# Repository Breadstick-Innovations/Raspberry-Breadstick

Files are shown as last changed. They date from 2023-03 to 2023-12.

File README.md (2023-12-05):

# Raspberry Breadstick
An RP2040 development board compatible with CircuitPython, MicroPython, and Arduino!
## Campaign Now Live!→ https://www.crowdsupply.com/breadstick-innovations/raspberry-breadstick
Rev0.2-17
Rev0.2 Render - Small Production Run Underway!
## A Breadstick for your Breadboard!
- Spaced out I/O pins eliminate long jumper wires
- RP2040 with 16MB of Flash Memory
- 24 SK9822 addressable RGB LEDs (Clock + Data) that are DotStar compatible
- 6-Axis IMU LSM6DSMTR (3-Axis Accellerometer + 3-Axis Gyroscope)
Rev0.2-Ortho-5
Rev0.2-25
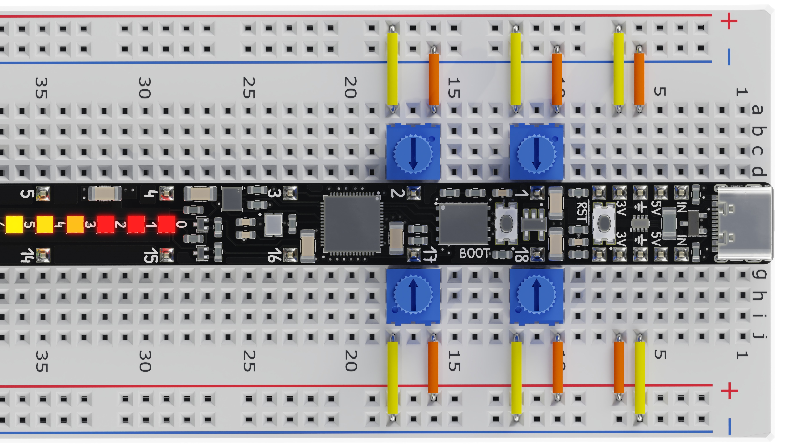
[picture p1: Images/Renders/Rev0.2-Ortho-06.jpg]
Rev0.2-Ortho-06

Rev0.2 Renders - Small Production Run Underway!
## Rev0.1 Demo Video
Rev0.1 Prototype Youtube (https://www.youtube.com/watch?v=IzdXLQIp9vg)
## Schematic
### RP2040 GPIO to Pin Definitions
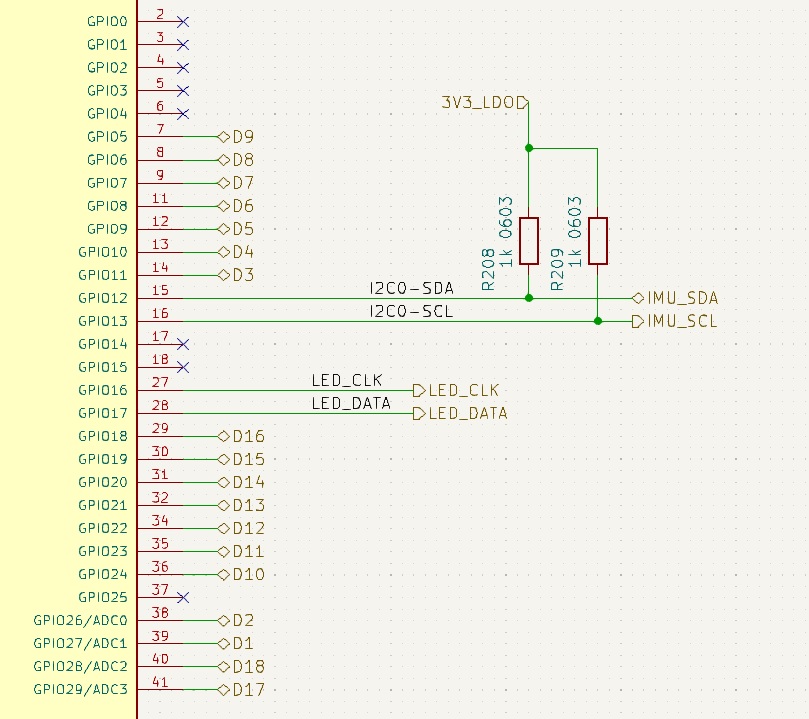
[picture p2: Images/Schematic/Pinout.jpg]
Pinout

### Overview
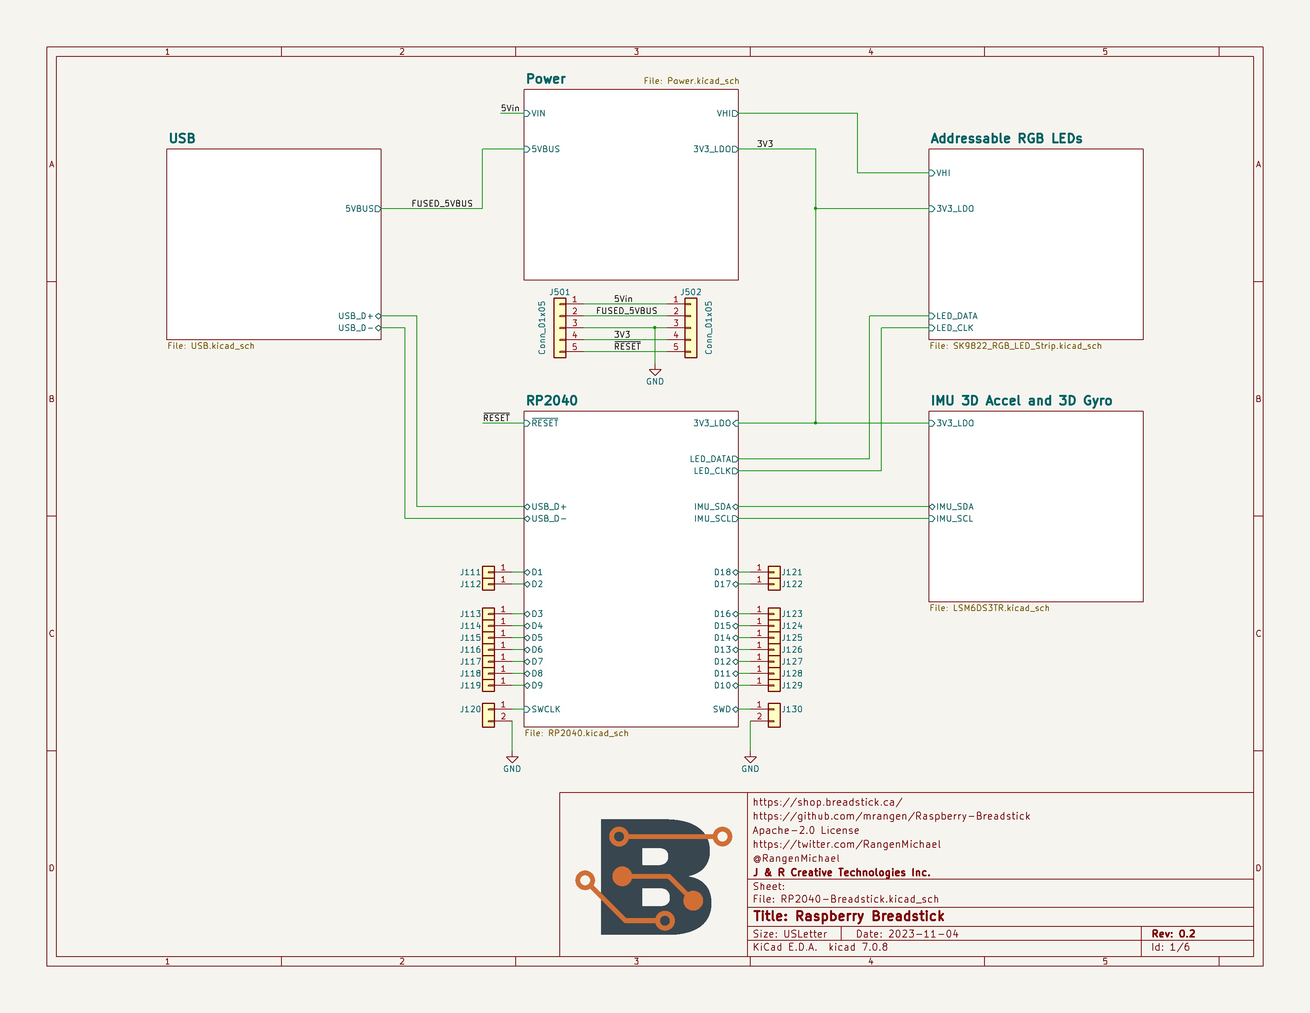
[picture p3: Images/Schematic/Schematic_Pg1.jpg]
Schematic_Pg1

### RP2040 Microcontroller
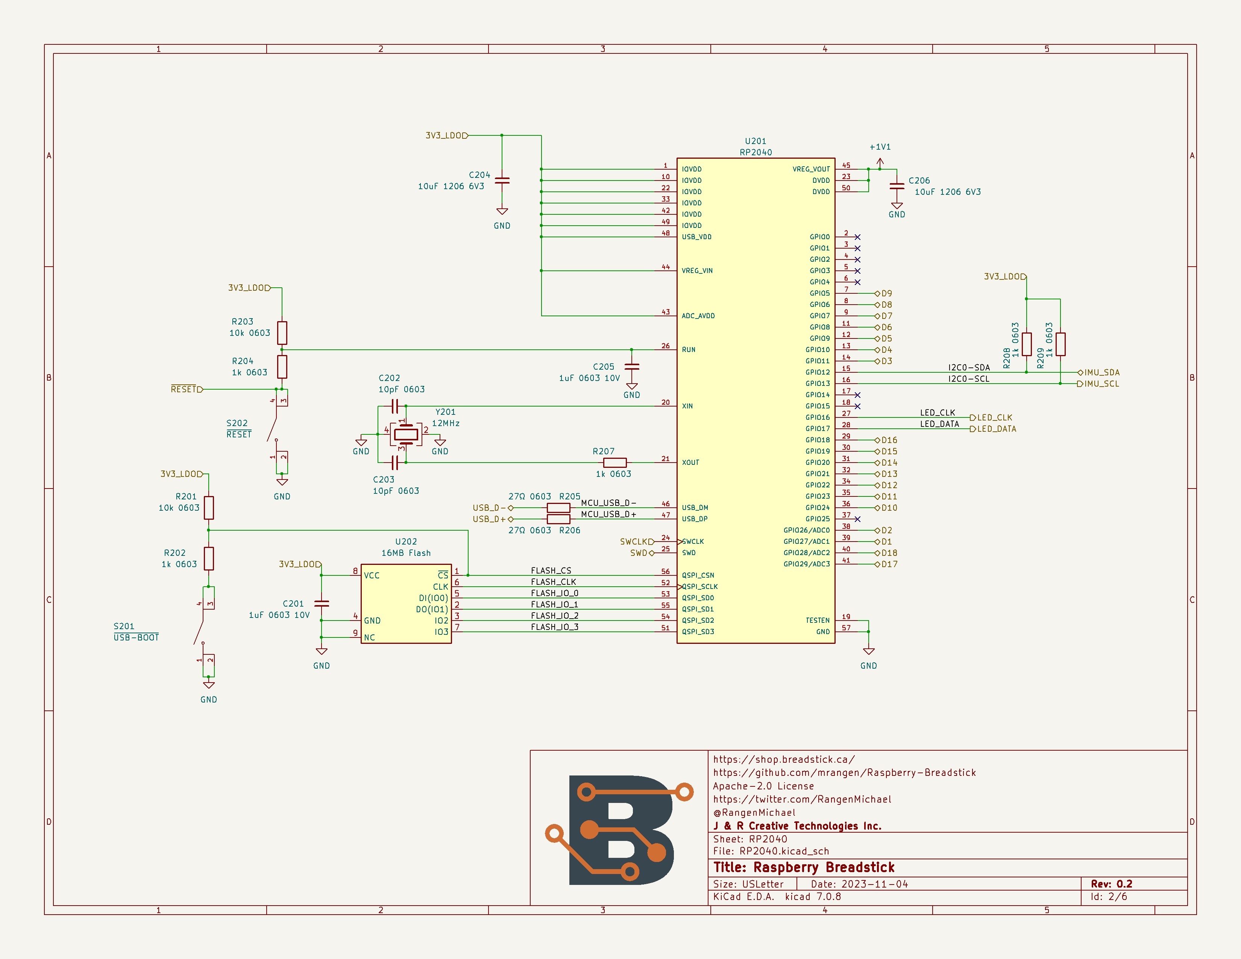
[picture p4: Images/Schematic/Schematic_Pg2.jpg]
Schematic_Pg2.

### SK9822 RGB LEDs
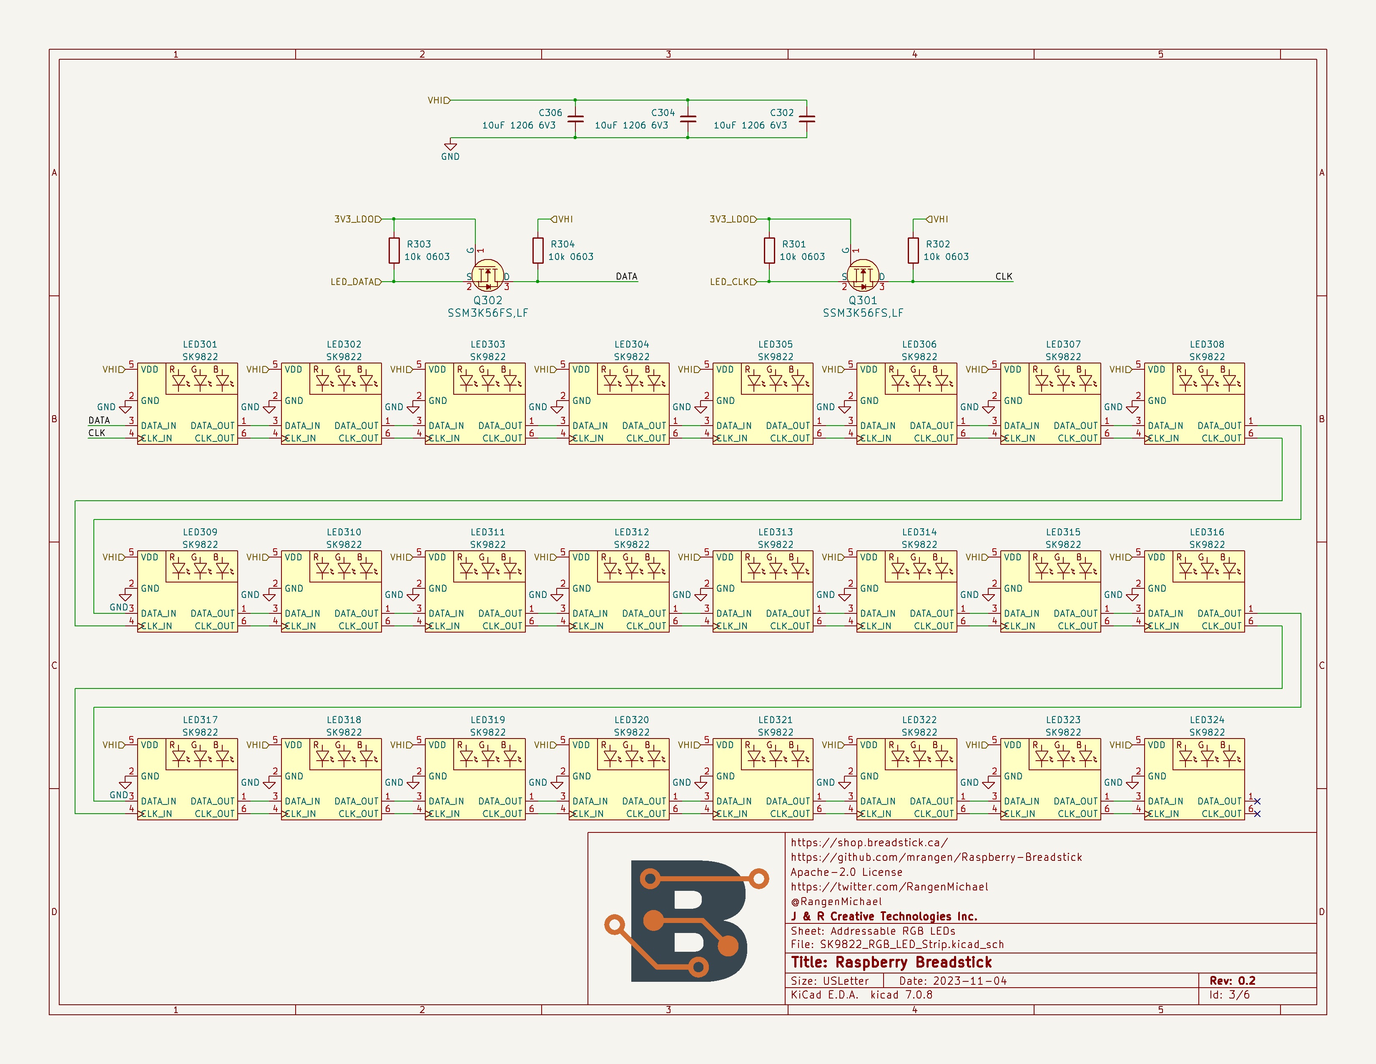
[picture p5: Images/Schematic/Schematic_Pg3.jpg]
Schematic_Pg3

### LSM6DSMTR 6-Axis IMU
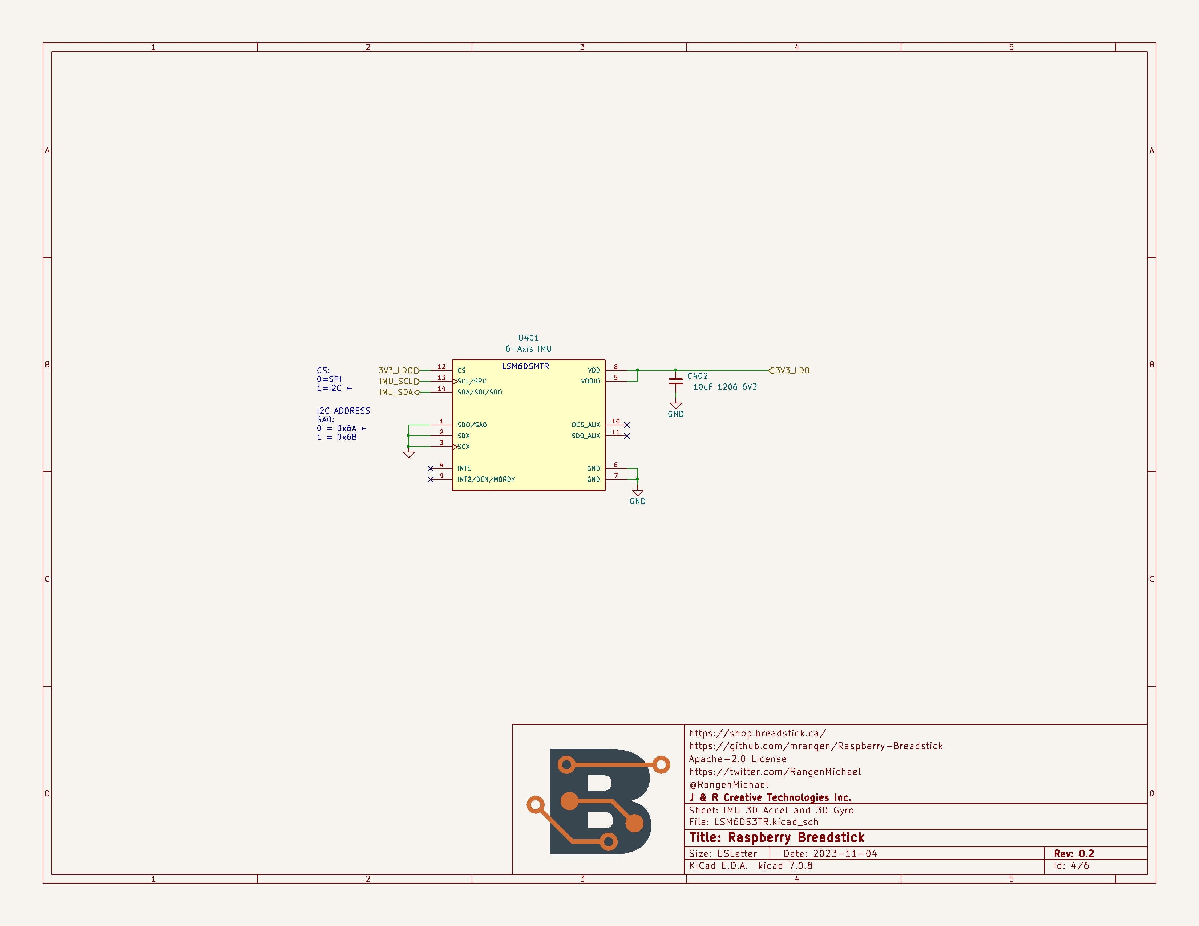
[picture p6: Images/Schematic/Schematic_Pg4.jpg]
Schematic_Pg4

### Power
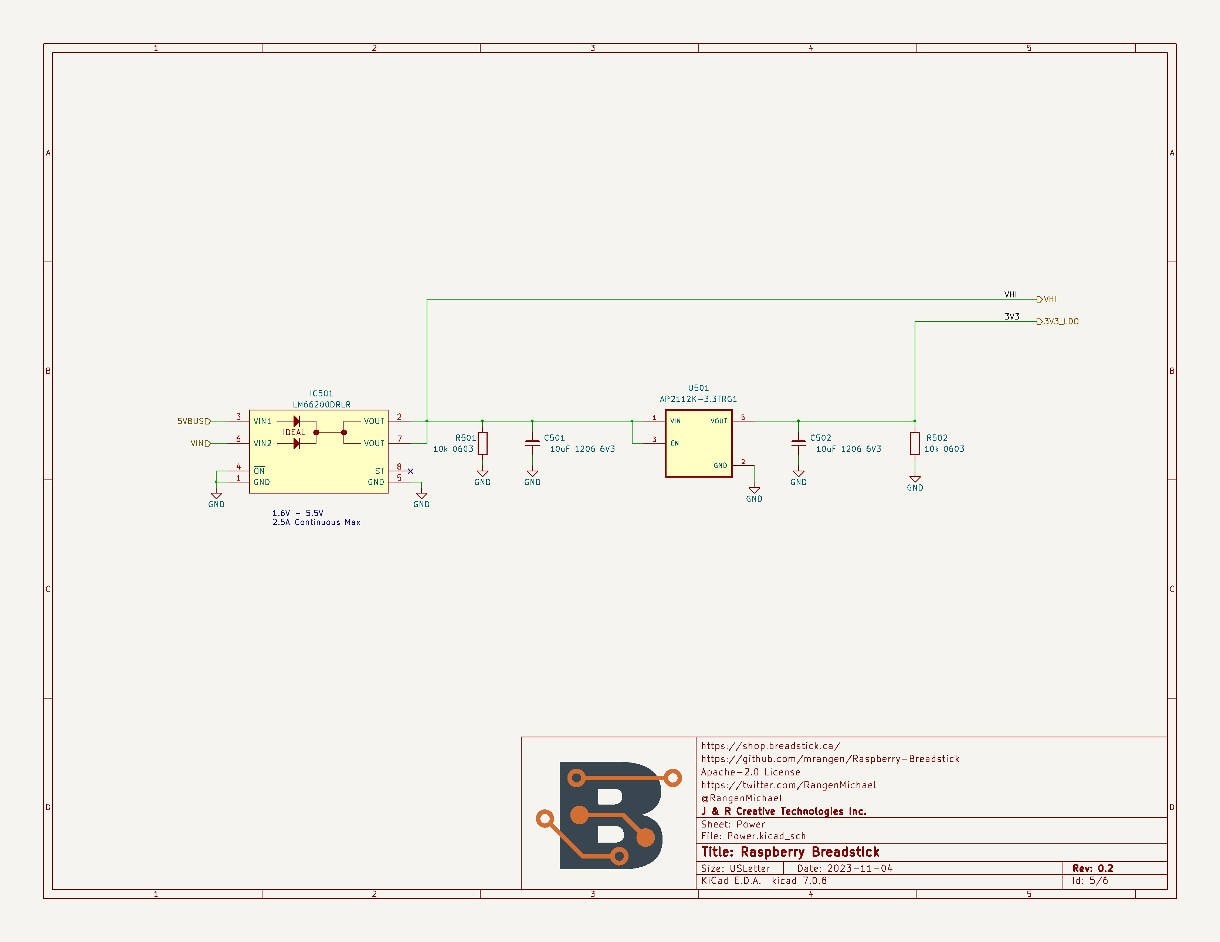
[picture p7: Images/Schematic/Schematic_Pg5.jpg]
Schematic_Pg5

### USB-C
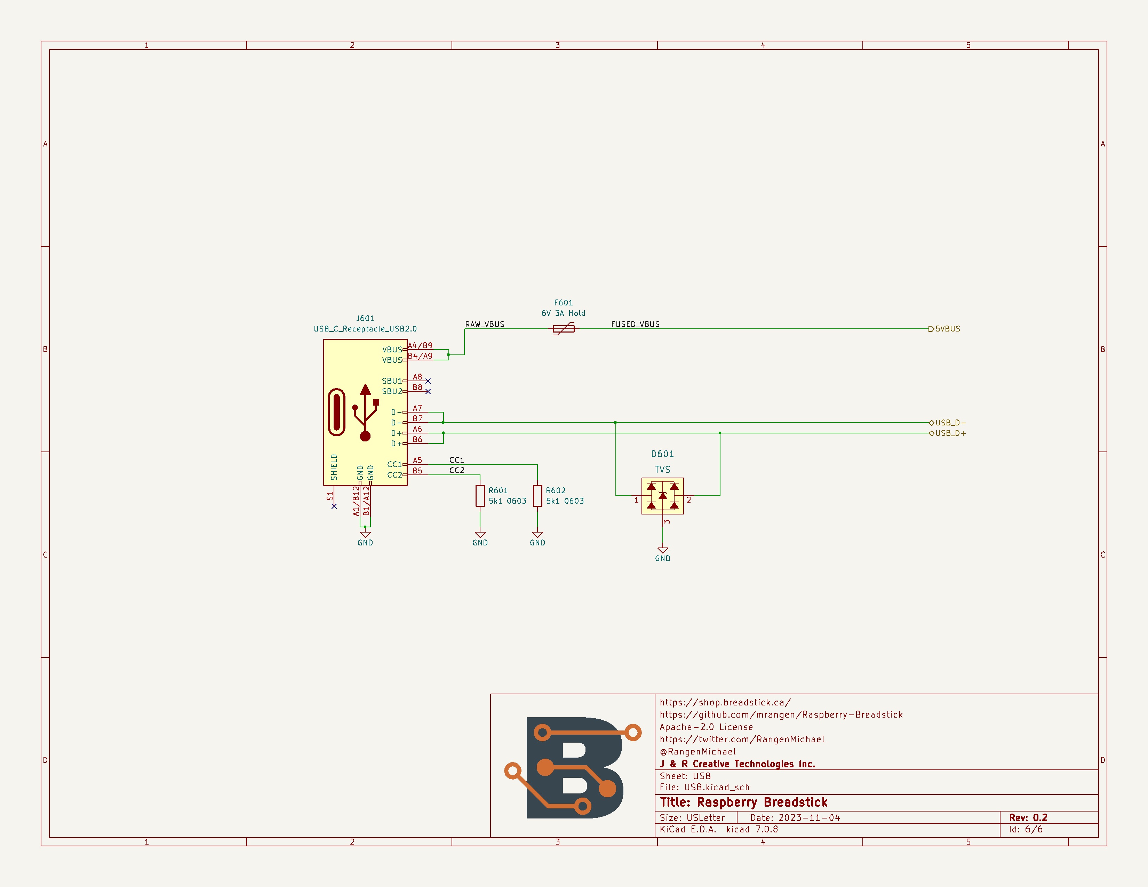
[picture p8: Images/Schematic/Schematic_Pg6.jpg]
Schematic_Pg6


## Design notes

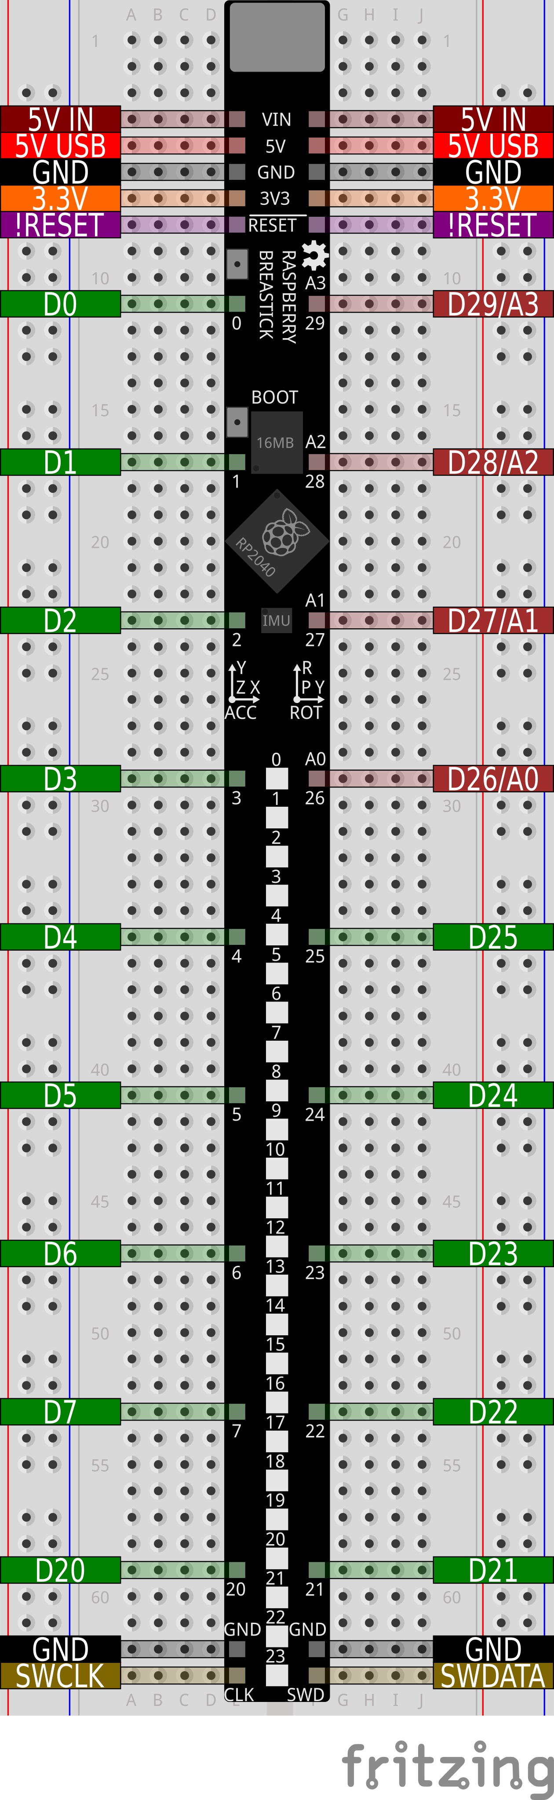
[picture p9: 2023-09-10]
RP2040-Breadstick/Pinout Diagram/RaspberryBreadstickPinout.jpg

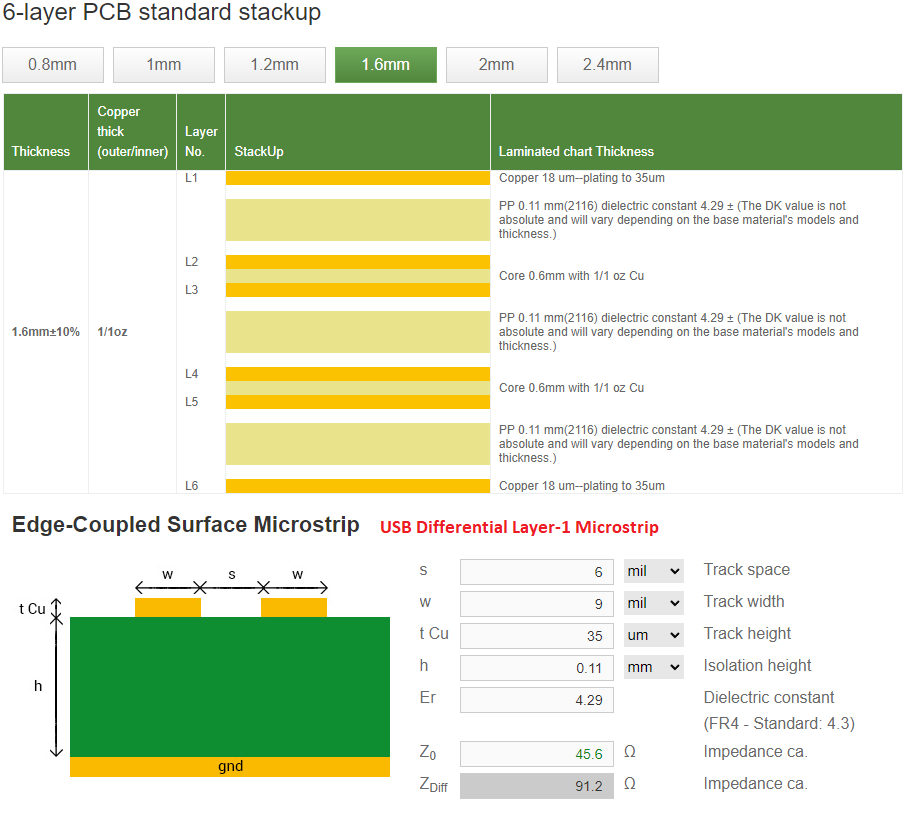
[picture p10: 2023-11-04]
6-Layer Stackup and Controlled Impedance.png

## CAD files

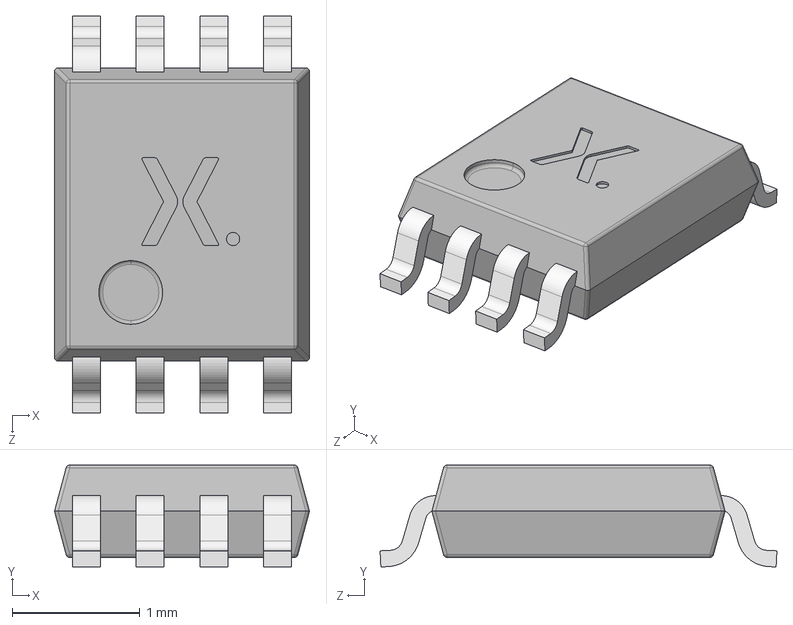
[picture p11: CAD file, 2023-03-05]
RP2040-Breadstick/Snap EDA/74AXP2T45DCH/74AXP2T45DCH.stp
2.00 x 0.8 x 3.11 mm
SOT765 Mold body
SOT765 Lead x 8

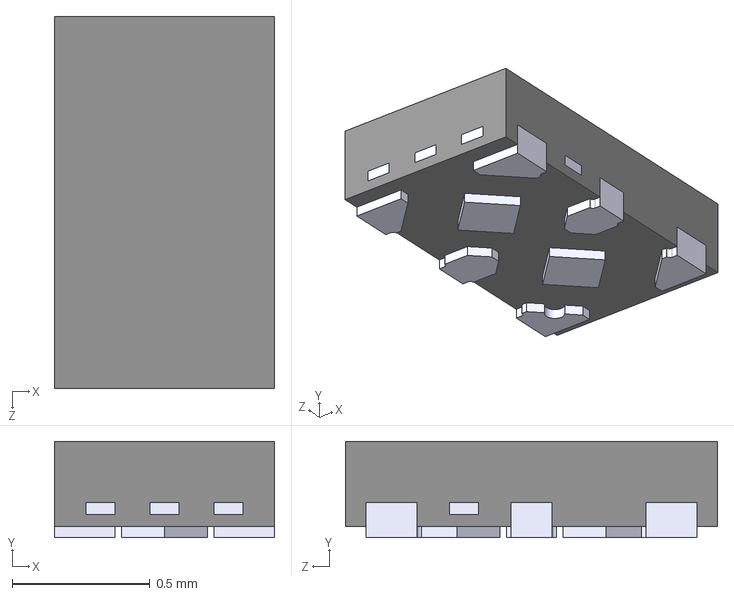
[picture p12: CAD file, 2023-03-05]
RP2040-Breadstick/Snap EDA/74AXP2T45GXX/74AXP2T45GXX.STEP
0.8 x 0.35 x 1.35 mm

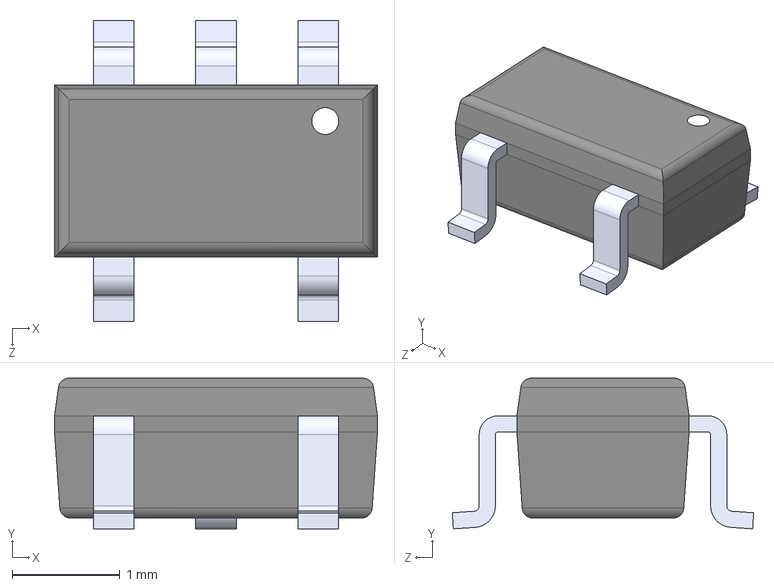
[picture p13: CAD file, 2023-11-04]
RP2040-Breadstick/Snap EDA/AP2112K-3.3TRG1/AP2112K-3.3TRG1.step
3.00 x 1.40 x 2.80 mm

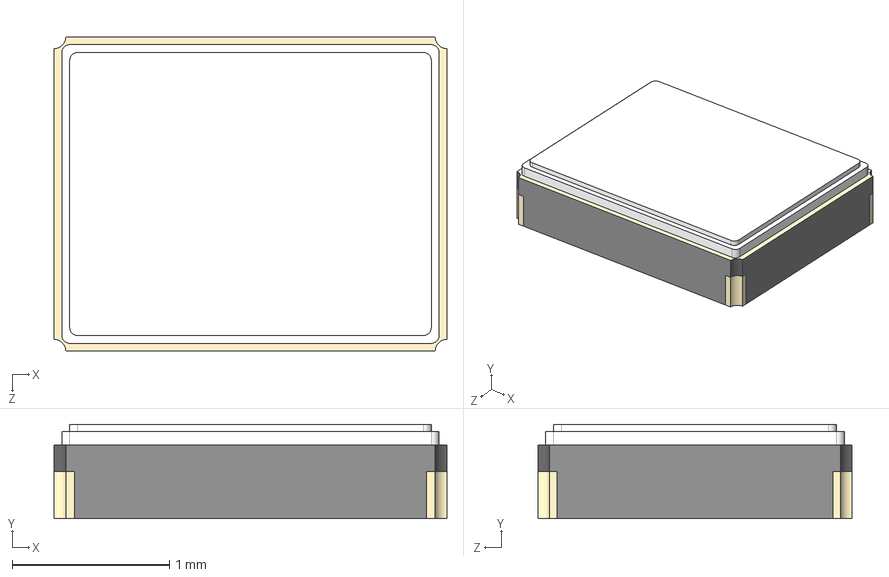
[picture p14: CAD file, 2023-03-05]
RP2040-Breadstick/Snap EDA/ECS-120-10-36Q-ES-TR/ECS-120-10-36Q-ES-TR.step
2.50 x 0.6 x 2.00 mm

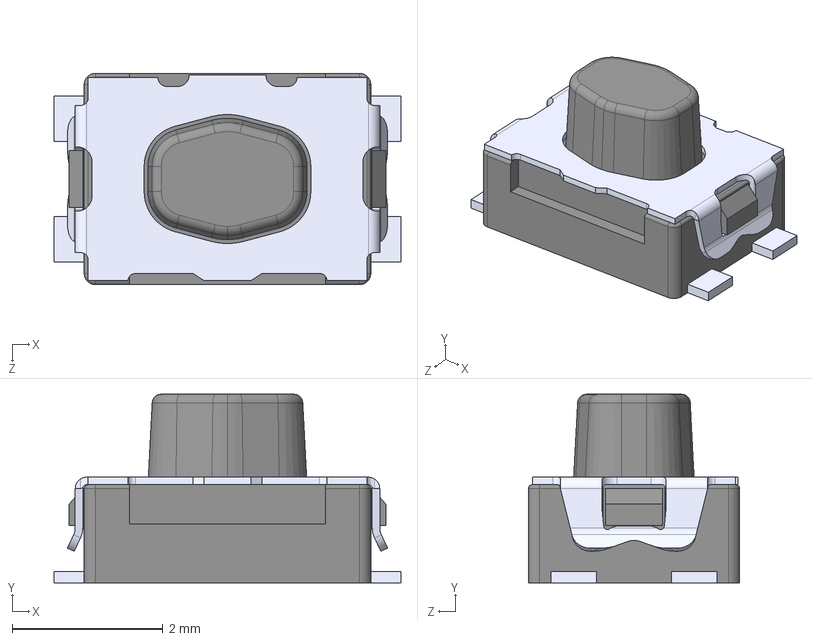
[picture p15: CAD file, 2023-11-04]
RP2040-Breadstick/Snap EDA/KMR731NGLFS/KMR731NGLFS.step
4.60 x 2.50 x 2.80 mm

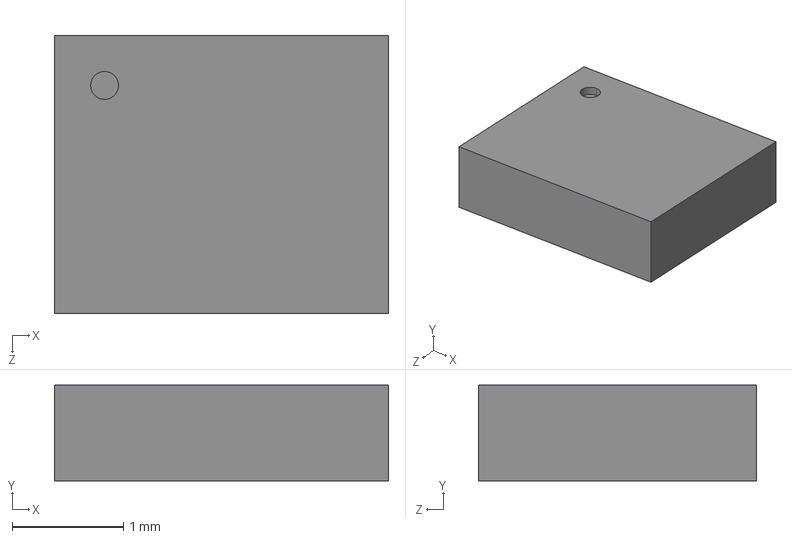
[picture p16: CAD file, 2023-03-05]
RP2040-Breadstick/Snap EDA/LSM6DSMTR/LSM6DSMTR.step
3.00 x 0.86 x 2.50 mm

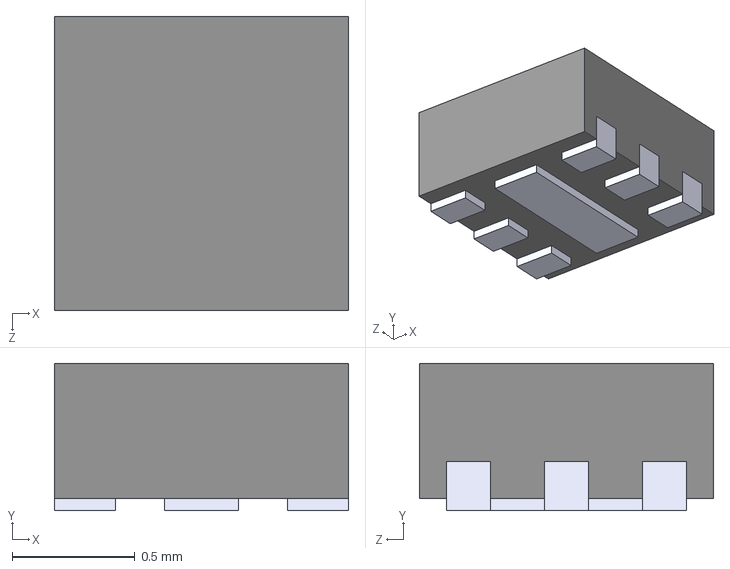
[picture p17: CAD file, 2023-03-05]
RP2040-Breadstick/Snap EDA/MIC5528-3.3YMT-TR/MIC5528-3.3YMT-TR.step
1.20 x 0.6 x 1.20 mm

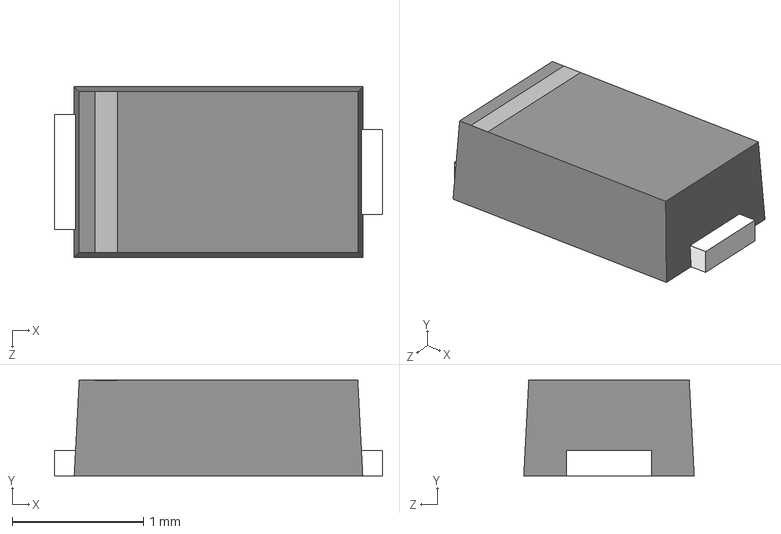
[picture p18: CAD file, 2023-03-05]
RP2040-Breadstick/Snap EDA/MICROSMP_DO-219AD/V2PM15HM3_H.step
2.50 x 0.73 x 1.30 mm

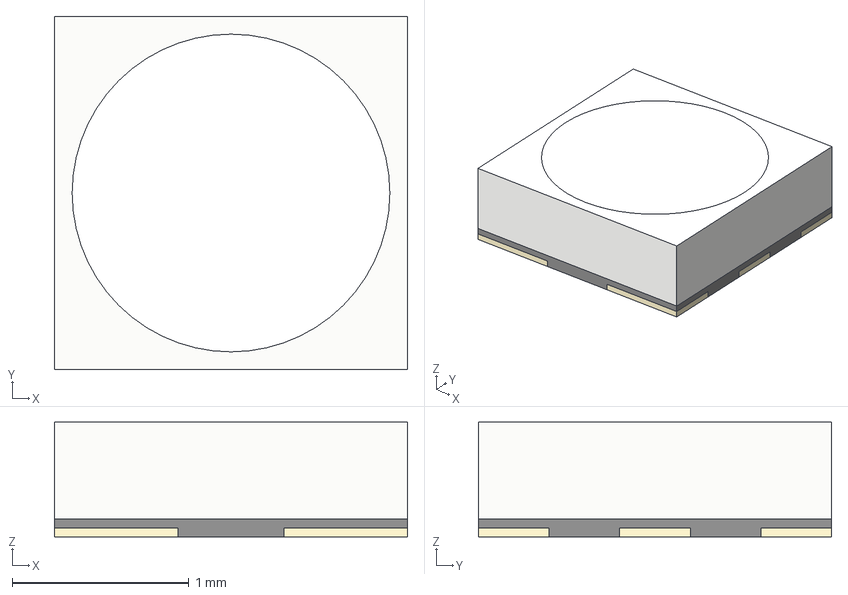
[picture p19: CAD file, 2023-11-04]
RP2040-Breadstick/Snap EDA/SK9822-2020 RGB LED v2.step
2.00 x 2.00 x 0.65 mm
SK9822-2020 RGB LED v2 v6
SK9822-2020 RGB LED v2 v007
SK9822-2020 RGB LED v2 v008
SK9822-2020 RGB LED v2 v009
SK9822-2020 RGB LED v2 v010
SK9822-2020 RGB LED v2 v011
SK9822-2020 RGB LED v2 v012
SK9822-2020 RGB LED v2 v013
SK9822-2020 RGB LED v2 v014
SK9822-2020 RGB LED v2 v015

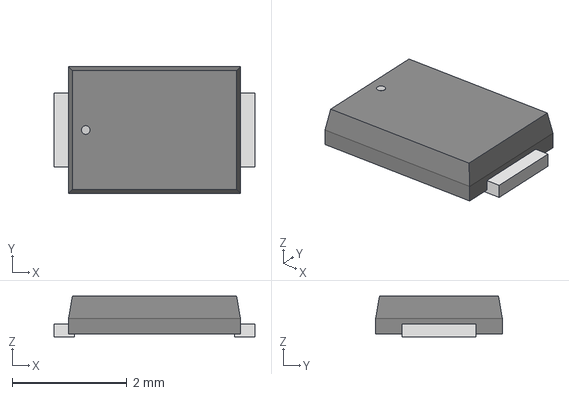
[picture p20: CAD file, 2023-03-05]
RP2040-Breadstick/Snap EDA/Switch_R-667995/2023-01-15_17-38-00/STEP/R-667995_MIT.step
3.51 x 2.21 x 0.714 mm

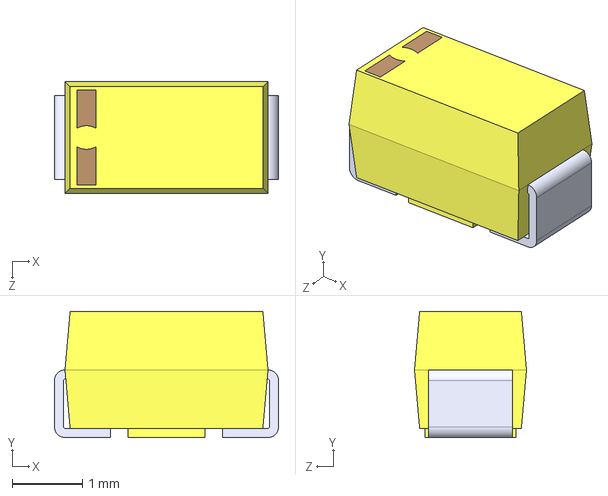
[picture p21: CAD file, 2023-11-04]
RP2040-Breadstick/Snap EDA/T491A106K010AT/T491A106K010AT.step
3.20 x 1.80 x 1.60 mm

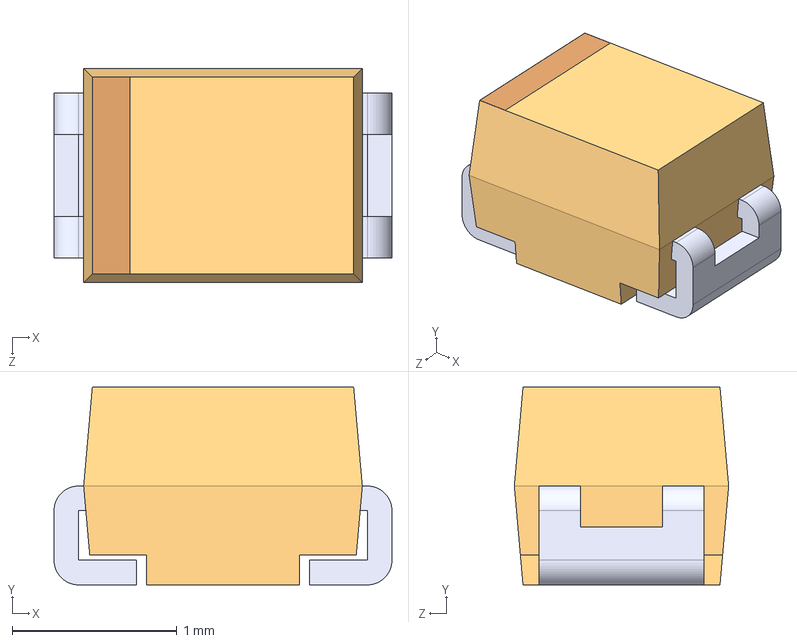
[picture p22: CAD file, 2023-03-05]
RP2040-Breadstick/Snap EDA/TLJR476M006R3200/TLJR476M006R3200.step
2.05 x 1.20 x 1.30 mm

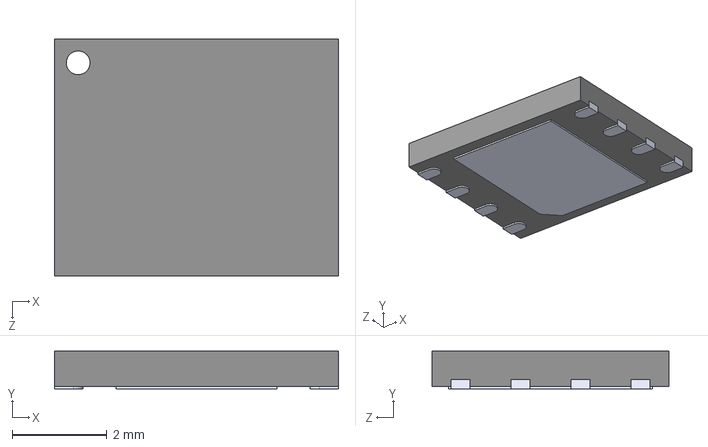
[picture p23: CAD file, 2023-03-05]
RP2040-Breadstick/Snap EDA/W25Q128JVPIQ-TR/W25Q128JVPIQ-TR.step
6.00 x 0.8 x 5.00 mm

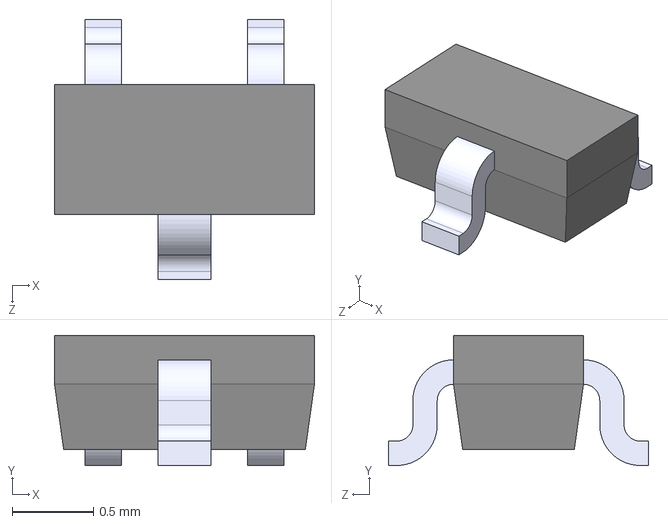
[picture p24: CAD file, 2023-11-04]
RP2040-Breadstick/Snap EDA/SOT-416.STEP
1.60 x 0.8 x 1.60 mm

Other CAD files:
RP2040-Breadstick/Snap EDA/LM66200DRLR/LM66200DRLR.stp
RP2040-Breadstick/Snap EDA/USB-C-2171790001/2171790001.stp
RP2040-Breadstick/Snap EDA/SK9822-2020 RGB LED v2_old.step

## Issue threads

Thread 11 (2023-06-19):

Replace ORing diodes with Ideal Diodes

mrangen, 2023-06-19:
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

Closed 2023-10-20.

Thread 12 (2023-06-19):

Design panel with mousebites away from pins

mrangen, 2023-06-19:
Avoid v-scoring - depanelling will just lead to ripped pads at edge.
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

codeman256, 2023-06-30:
This was my current plan for panelling.
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

mrangen, 2023-07-01:
That looks pretty good but I think we might need additional mouse-bites. I'd rather err on the side of too many than too few for the first panels.
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

mrangen, 2023-07-01:
We should also look into standard panel sizes and make sure that we're not designing a panel that's awkward or wasteful for typical assembly machines. Might be worth asking the manufacturer to give a penalization recommendation.

Closed 2023-11-14.

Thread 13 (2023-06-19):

Add more paste to USB-C Connector

mrangen, 2023-06-19:
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

codeman256, 2023-06-30:
I'm sure I can do this. is there an estimate on how much more paste? 2x or 1.5x?

mrangen, 2023-07-01:
Based on how the first assembled batch came out, this should be enough:
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

Closed 2023-10-20.

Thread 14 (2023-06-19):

Fix TVS diode path to ground

mrangen, 2023-06-19:
Add a via to ground immediately beside the TVS diode.
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

Closed 2023-10-20.

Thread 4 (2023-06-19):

Show signals between hierarchical sheets

mrangen, 2023-06-19:

mrangen, 2023-06-19:
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

codeman256, 2023-06-30:
What do you figure you want to do with this? make the chip the top page then have the sub circuits the sub pages?

mrangen, 2023-07-01:
Something like that shows important signals and power routing between sheets like this: https://embeddedcomputing.com/technology/analog-and-power/kicad-hierarchical-sheets-for-enhanced-schematics

Closed 2023-10-20.

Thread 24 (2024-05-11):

Magic Wand of HarryPotter

JpEncausse, 2024-05-11:
Hello,
I was wondering if someone already did a HarryPotter Magic Wand to recognize gesture ?
- I know [there is some arduino code](https://github.com/boilingbrains/BaguetteMagiqueArduino/blob/main/CodesArduino/IMU_Classifier_Baguette_v2.ino) involving Tensorflow.
- Few year ago a company made a close source harrypotter wand.

It woudl be so cool to be able to recognize gesture and send HTTP Request for instance or special LED effect.

mrangen, 2024-05-12:
That's a very cool idea! I haven't played with machine learning on microcontrollers yet, but I bet it can be done. Hopefully someone in the community with experience will post some code!

JpEncausse, 2024-05-13:
I hope too :-) I used to play with PlatformIO on ESP-32 but I don't know CircuitPython and TensorFlow.
I assume each gesture could trigger a LED effect + HTTP request :-)

From Kano in 2018 : https://www.youtube.com/watch?v=wt9rK82l-io

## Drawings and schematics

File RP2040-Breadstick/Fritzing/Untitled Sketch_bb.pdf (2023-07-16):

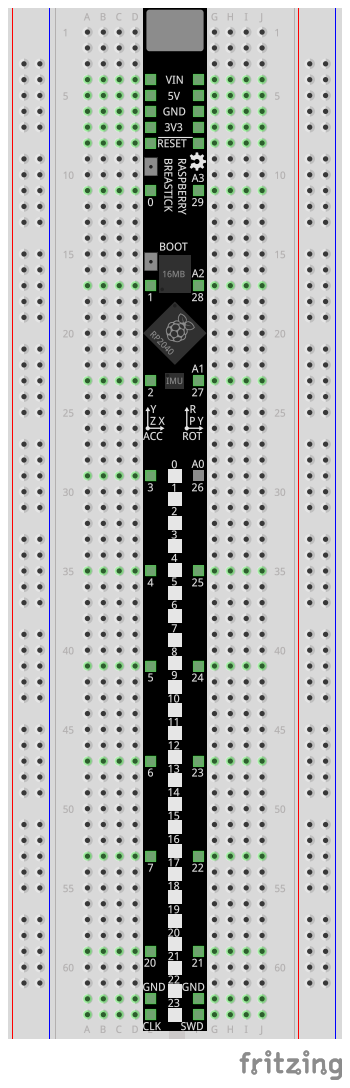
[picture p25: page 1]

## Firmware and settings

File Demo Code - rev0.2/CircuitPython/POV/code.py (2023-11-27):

# SPDX-FileCopyrightText: 2017 Limor Fried for Adafruit Industries
#
# SPDX-License-Identifier: MIT

# Dotstar painter! Can handle up to ~2300 pixel size image (e.g. 36 x 64)

import gc
import time

import board
import busio
import bitbangio
import digitalio
from adafruit_lsm6ds import Rate, AccelRange, GyroRange
from adafruit_lsm6ds.lsm6ds3trc import LSM6DS3TRC as LSM6DS

i2c = busio.I2C(board.IMU_SCL, board.IMU_SDA)
IMU = LSM6DS(i2c)

IMU.accelerometer_range = AccelRange.RANGE_4G
print("Accelerometer range set to: %d G" % AccelRange.string[IMU.accelerometer_range])

IMU.gyro_range = GyroRange.RANGE_1000_DPS
print("Gyro range set to: %d DPS" % GyroRange.string[IMU.gyro_range])

IMU.accelerometer_data_rate = Rate.RATE_1_66K_HZ
print("Accelerometer rate set to: %d HZ" % Rate.string[IMU.accelerometer_data_rate])

IMU.gyro_data_rate = Rate.RATE_1_66K_HZ
print("Gyro rate set to: %d HZ" % Rate.string[IMU.gyro_data_rate])


FILENAME = "CrowdSupply2.bmp"

IMAGE_DELAY = 0.001
REPEAT = True
BRIGHTNESS = 0.25
PIXEL_DELAY = 0.001

dotstar = bitbangio.SPI(board.DOTSTAR_CLOCK, board.DOTSTAR_DATA)
while not dotstar.try_lock():
    pass
dotstar.configure(baudrate=12000000)

# we'll resize this later
databuf = bytearray(0)

led = digitalio.DigitalInOut(board.D13)
led.switch_to_output()


def read_le(s):
    # as of this writting, int.from_bytes does not have LE support, DIY!
    result = 0
    shift = 0
    for byte in bytearray(s):
        result += byte << shift
        shift += 8
    return result


class BMPError(Exception):
    pass


try:
    with open("/" + FILENAME, "rb") as f:
        print("File opened")
        if f.read(2) != b'BM':  # check signature
            raise BMPError("Not BitMap file")

        bmpFileSize = read_le(f.read(4))
        f.read(4)  # Read & ignore creator bytes

        bmpImageoffset = read_le(f.read(4))  # Start of image data
        headerSize = read_le(f.read(4))
        bmpWidth = read_le(f.read(4))
        bmpHeight = read_le(f.read(4))
        flip = True

        print("Size: %d\nImage offset: %d\nHeader size: %d" %
              (bmpFileSize, bmpImageoffset, headerSize))
        print("Width: %d\nHeight: %d" % (bmpWidth, bmpHeight))

        if read_le(f.read(2)) != 1:
            raise BMPError("Not singleplane")
        bmpDepth = read_le(f.read(2))  # bits per pixel
        print("Bit depth: %d" % (bmpDepth))
        if bmpDepth != 24:
            raise BMPError("Not 24-bit")
        if read_le(f.read(2)) != 0:
            raise BMPError("Compressed file")

        print("Image OK!")

        rowSize = (bmpWidth * 3 + 3) & ~3  # 32-bit line boundary

        # its huge! but its also fast :)
        databuf = bytearray(bmpWidth * bmpHeight * 4)

        for row in range(bmpHeight):  # For each scanline...
            if flip:  # Bitmap is stored bottom-to-top order (normal BMP)
                pos = bmpImageoffset + (bmpHeight - 1 - row) * rowSize
            else:  # Bitmap is stored top-to-bottom
                pos = bmpImageoffset + row * rowSize

            # print ("seek to %d" % pos)
            f.seek(pos)
            for col in range(bmpWidth):
                b, g, r = bytearray(f.read(3))  # BMP files store RGB in BGR
                # front load brightness, gamma and reordering here!
                order = [b, g, r]
                idx = (col * bmpHeight + (bmpHeight - row - 1)) * 4
                databuf[idx] = 0xFF  # first byte is 'brightness'
                idx += 1
                for color in order:
                    databuf[idx] = int(
                        pow((color * BRIGHTNESS) / 255, 2.7) * 255 + 0.5)
                    idx += 1

except OSError as e:
    if e.args[0] == 28:
        raise OSError("OS Error 28 0.25")
    else:
        raise OSError("OS Error 0.5")
except BMPError as e:
    print("Failed to parse BMP: " + e.args[0])

gc.collect()
print(gc.mem_free())
print("Ready to go!")
while True:
    #print("Draw!")
    index = 0

    #acc_x, acc_y, acc_z = IMU.acceleration
    gyro_x, gyro_z, gyro_z = IMU.gyro
    #print(gyro_z)
    #time.sleep(0.05)



    if(gyro_z<0):
        for col in range(bmpWidth):
            gyro_x, gyro_z, gyro_z = IMU.gyro
            if(gyro_z<0):
                pass
            else:
                break
            index = bmpHeight * 4 * col
            row = databuf[index:index + bmpHeight * 4]
            dotstar.write(bytearray([0x00, 0x00, 0x00, 0x00]))
            dotstar.write(row)
            dotstar.write(bytearray([0x00, 0x00, 0x00, 0x00]))
            #index += bmpHeight * 4
            if(abs(gyro_z)<0.001): gyro_z = 0.001
            time.sleep(abs(PIXEL_DELAY/gyro_z))

    else:
        for col in range(bmpWidth,-1,-1):
            gyro_x, gyro_z, gyro_z = IMU.gyro
            if(gyro_z<0):
                break
            else:
                pass
            index = bmpHeight * 4 * col
            row = databuf[index:index + bmpHeight * 4]
            dotstar.write(bytearray([0x00, 0x00, 0x00, 0x00]))
            dotstar.write(row)
            dotstar.write(bytearray([0x00, 0x00, 0x00, 0x00]))
            #index += bmpHeight * 4
            if(abs(gyro_z)<0.001): gyro_z = 0.001
            time.sleep(abs(PIXEL_DELAY/gyro_z))


    # clear it out
    dotstar.write(bytearray([0x00, 0x00, 0x00, 0x00]))
    for r in range(bmpHeight * 5):
        dotstar.write(bytearray([0xFF, 0x00, 0x00, 0x00]))
    dotstar.write(bytearray([0xff, 0xff, 0xff, 0xff]))
    gc.collect()

    if not REPEAT:
        break

    time.sleep(IMAGE_DELAY)

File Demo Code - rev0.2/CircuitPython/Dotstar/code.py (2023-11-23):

import time
import random
import board
import adafruit_dotstar as dotstar
import adafruit_fancyled.adafruit_fancyled as fancy

def random_color():
    return random.randrange(0, 7) * 32

num_leds = 24

dots = dotstar.DotStar(board.DOTSTAR_CLOCK, board.DOTSTAR_DATA, num_leds, brightness=1.0, auto_write=False)

offset = 0  # Positional offset into color palette to get it to 'spin'

while True:
    for i in range(num_leds):
        c = fancy.CRGB(fancy.CHSV(i/num_leds+offset,1.0,0.05))
        dots[i] = c.pack()
    dots.show()

    offset += 0.02  # Bigger number = faster spin

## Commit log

2022-07-19 Worked on breakout board for 3DAccel+3DGyro
    [3DAccel_3DGyro_LSM6DS3TR.kicad_pcb, 3DAccel_3DGyro_LSM6DS3TR.kicad_sch]
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2022-07-26 Created main rp2040breadstick project
    [7V12000018 v4.step, BOM.xlsx, Crystal3225_24GND.step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]
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2022-07-27 Replaced USB ESD and 0402 passives with 0201 where possible.
    [RP2040-Breadstick.kicad_sch, RP2040.kicad_sch, TPD4E05U06DQAR.step]
2022-07-29 Created footprint and 3D model for SK9822 RGB LEDs, still need symbol
    [RP2040.kicad_sch, SK9822-2020 RGB LED v2.step]
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2022-08-01 Added input and termination resistors for LED strip
    [RP2040-Breadstick.kicad_sch, SK9822_RGB_LED_Strip.kicad_sch]
2022-08-01 Added IMU and Power Sheets
    [LSM6DS3TR.kicad_sch, Power.kicad_sch, RP2040-Breadstick.kicad_sch]
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2022-08-01 IMU Pins and Power Supply updated
    [LSM6DS3TR.kicad_sch, Power.kicad_sch, RP2040-Breadstick.kicad_sch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]
2022-08-02 Added level shifter for LEDs and fixed footprint associations for LEDs
    [RP2040-Breadstick.kicad_sch, SK9822_RGB_LED_Strip.kicad_sch, TXB0102DCUR.step]
2022-08-02 Schematic Rough Draft Complete
    [LSM6DS3TR.kicad_sch, Power.kicad_sch, RP2040-Breadstick.kicad_sch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]
2022-08-02 Created PCB file, board setup/stackup needs to be done yet.
    [LSM6DS3TR.kicad_sch, RP2040-Breadstick.kicad_pcb, RP2040.kicad_sch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]
2022-08-02 Added pull-down resistor to level-shifter
    [LSM6DS3TR.kicad_sch, RP2040-Breadstick.kicad_sch, SK9822_RGB_LED_Strip.kicad_sch]
2022-08-04 Initial PCB organization complete.
    [Power.kicad_sch, RP2040-Breadstick.kicad_pcb, RP2040-Breadstick.kicad_sch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]
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2022-08-05 Calculated 50Ω on Layer 5 and Added Ground Planes to Layers 2, 4, & 6
    [RP2040-Breadstick.kicad_pcb]
2022-08-05 Added note: What's true on layer 5 is also true on layer 3.
    [RP2040-Breadstick.kicad_pcb]
2022-08-05 Corrected comment: Layers 3 and 5 have different characteristics!!
    [RP2040-Breadstick.kicad_pcb]
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2022-08-06 Fixed issue with Perfect 0201 R and C being off-center
    [RP2040-Breadstick.kicad_pcb]
2022-08-06 Components roughly in place, added 3.3V copper pour to layers 1 and 3 for even distribution.
    [RP2040-Breadstick.kicad_pcb, RP2040-Breadstick.kicad_sch, RP2040.kicad_sch]
2022-08-09 Added fuse to VBus, Fixed ESD to allow pasthrough on unused pins, began laying USB and power signals.
    [Power.kicad_sch, RP2040-Breadstick.kicad_pcb, RP2040-Breadstick.kicad_sch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]
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2022-08-10 Rearranged LDO and Flash IC, routing first half of board.
    [Power.kicad_sch, RP2040-Breadstick.kicad_pcb]
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2022-08-23 Reassigned IMU and Level Shifter Pins, experimented routing.
    [RP2040-Breadstick.kicad_pcb, RP2040.kicad_sch]
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2022-09-03 Routing to Flash IC done, removed 0402 capacitors from the LDO
    [Power.kicad_sch, RP2040-Breadstick.kicad_pcb, RP2040-Breadstick.kicad_sch]
2023-01-15 8-Layer Stackup Entered, Replaced a number of components, Digikey BOM built
    [2171790001.stp, LSM6DS3TR.kicad_sch, Power.kicad_sch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]
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2023-01-15 Brought new parts and associated footprints into schematic
    [74AXP2T45GXX.STEP, ECS-120-10-36Q-ES-TR.step, LSM6DS3TR.kicad_sch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]
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2023-01-15 Initial Schematic Done, footprints roughly grouped on PCB
    [LSM6DS3TR.kicad_sch, Power.kicad_sch, RP2040-Breadstick.kicad_pcb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]
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2023-02-20 Replaced Logic Converter and Routed LED Signals, rotated LED Caps
    [74AXP2T45DCH.stp, RP2040-Breadstick.kicad_pcb, RP2040-Breadstick.kicad_sch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]
2023-02-21 Moved QSPI traces to bottom to clear inner signal path and created room for USB traces
    [RP2040-Breadstick.kicad_pcb, SK9822_RGB_LED_Strip.kicad_sch]
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2023-02-26 Added ground pins to bottom of board, continuing to clean up traces and vias.
    [Power.kicad_sch, RP2040-Breadstick.kicad_pcb, RP2040-Breadstick.kicad_sch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]
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2023-02-27 Updated reset circuit and continued optimizing trace paths
    [RP2040-Breadstick.kicad_pcb, RP2040-Breadstick.kicad_sch, RP2040.kicad_sch]
2023-02-27 Worked on clearing design rule errors and added solder paste to USB mounting pins
    [RP2040-Breadstick.kicad_pcb, RP2040.kicad_sch]
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2023-03-01 fixed USB-C port with Mike
    [RP2040-Breadstick-B_Fab.gbr, RP2040-Breadstick-B_Mask.gbs, RP2040-Breadstick-B_Paste.gbp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]
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2023-03-09 Front FAB layout fixed
    [RP2040-Breadstick-B_Fab.gbr, RP2040-Breadstick-B_Mask.gbr, RP2040-Breadstick-B_Mask.gbs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]
2023-03-09 Fixed back FAB
    [RP2040-Breadstick.kicad_pcb]
2023-03-09 gerber fixes for allpcb
    [RP2040-Breadstick-B_Fab.gbr, RP2040-Breadstick-B_Mask.gbr, RP2040-Breadstick-B_Paste.gbr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]
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2023-03-21 solder mask min pad opening set to 8mil
    [RP2040-Breadstick.kicad_pcb]
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2023-05-18 Added a note about adding ideal ORing diodes IC
    [Power.kicad_sch]
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2023-07-02 Reduced PCB to 6 layers: Sig, Gnd, Sig, Gnd, Sig, Pow
    I'm going to need to re-route and reposition a number of components. Going to focus on changes to schematic and parts before coming back to the PCB.
    [RP2040-Breadstick.kicad_pcb]
2023-07-03 Working on several issues simultaneously from the schematic side.
    Added hierarchical connections between schematic sheets.
    Added ideal ORing diodes.
    Unstacked Pins and Added internal diagrams to: USB connector, TVS Diodes, ORing Diodes, LDO, RP2040, etc.
    [LM66200DRLR.stp, LSM6DS3TR.kicad_sch, Power.kicad_sch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]
2023-07-03 Continued cleaning up schematic
    Finished most of the microcontroller sheet.
    Added hierarchical pins to LED and IMU sheets.
    Replaced 24 caps for the LEDs with 6 1206 caps.
    [LSM6DS3TR.kicad_sch, RP2040-Breadstick.kicad_sch, RP2040.kicad_sch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]
2023-07-03 Moved schematic changes into PCB
    All the changes made in the schematic have been moved into the PCB editor. It was a bit of work due to the amount of reorganizing done in the schematic which led to a lot of new reference numbers. Wa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
    [LSM6DS3TR.kicad_sch, Power.kicad_sch, RP2040-Breadstick.kicad_pcb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]
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2023-07-17 Moved All Parts to Top
    Exploring how this can be done with the largest components possible, all on the top side of the board.
    [Power.kicad_sch, RP2040-Breadstick.kicad_pcb, RP2040-Breadstick.kicad_sch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]
2023-09-10 added labels to the flash mem lines, set defaults to 6mil traces, 0.3mm vias
    [RP2040-Breadstick.kicad_pcb, RP2040.kicad_sch, SK9822_RGB_LED_Strip.kicad_sch]
2023-09-11 continued working on all issues, began routing.
    [RP2040-Breadstick.kicad_pcb, RP2040-Breadstick.kicad_sch, RP2040.kicad_sch]
2023-09-11 Changed stackup to Sig, Gnd, Pow, Sig, Gnd, Sig
    [RP2040-Breadstick.kicad_pcb]
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2023-09-14 Finished assigning I/O pins, perfect is the enemy of good.
    [AP2112K-3.3TRG1.step, Power.kicad_sch, RP2040-Breadstick.kicad_pcb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]
2023-09-14 replaced switches, upsized some passives to 0603
    [KMR731NGLFS.step, Power.kicad_sch, RP2040-Breadstick.kicad_pcb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]
2023-09-16 Rough routing complete, time to polish it a bit
    [Power.kicad_sch, RP2040-Breadstick.kicad_pcb, RP2040-Breadstick.kicad_sch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]
2023-09-16 Ready for a quote, need to take a closer look at the copper fill zone.
    The board is long and thin, to prevent warpage the copper on each layer should be balanced i.e. the very empty areas filled.
    [RP2040-Breadstick-B_Fab.gbr, RP2040-Breadstick-B_Mask.gbr, RP2040-Breadstick-B_Paste.gbr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]
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2023-09-19 replaced logic level translator IC with discrete n-chan mosfets
    [RP2040-Breadstick.kicad_pcb, RP2040-Breadstick.kicad_sch, RP2040.kicad_sch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]
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2023-09-23 Updated crystal caps part numbers in BOM from 0201 to 0603
    [LSM6DS3TR.kicad_sch, Power.kicad_sch, RP2040-Breadstick.kicad_sch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]
2023-09-29 Fixed BOM and Silkscreen
    [RP2040-Breadstick.kicad_pcb, RaspberryBreadstickBOM.xlsx]
2023-10-02 Swapped Tantalum Caps for MLCC, added CE, UKCA, RoHS symbols
    [LSM6DS3TR.kicad_sch, Power.kicad_sch, RP2040-Breadstick.kicad_pcb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]
2023-10-09 just repositioning a couple things to make it neat looking
    [LSM6DS3TR.kicad_sch, Power.kicad_sch, RP2040-Breadstick.kicad_sch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]
2023-10-09 applied worksheet template
    changed worksheet template to breadstick library worksheet with logo
    [LSM6DS3TR.kicad_sch, Power.kicad_sch, RP2040-Breadstick.kicad_sch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]
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2023-10-11 things mike needs to fix
    [LSM6DS3TR.kicad_sch, RP2040-Breadstick.kicad_pcb, RP2040.kicad_sch]
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2023-10-18 Fixed BOM issues, adjusted wires, updated silkscreen
    [LSM6DS3TR.kicad_sch, Power.kicad_sch, RP2040-Breadstick.kicad_pcb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]
2023-10-18 created and replaced 2pin header for botton
    [RP2040-Breadstick.kicad_pcb, RP2040-Breadstick.kicad_sch]
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2023-11-04 Cleaned up schematic, added renders, made images for documentation
    [LSM6DS3TR.kicad_sch, Power.kicad_sch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]
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2023-11-04 Fixed pinout labels
    [LSM6DS3TR.kicad_sch, RP2040-Breadstick.kicad_pcb, RP2040-Breadstick.kicad_sch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]
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2024-02-08 Update RP2040-Breadstick.kicad_pcb
    added named pin silkscreen labels
    moved big logos off back.
    added Raspberry Breadstick name on front in mask
    [RP2040-Breadstick.kicad_pcb]
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
